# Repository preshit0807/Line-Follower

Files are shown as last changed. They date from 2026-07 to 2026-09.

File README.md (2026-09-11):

# Line Follower

An ESP32-based line-following robot with a custom PCB, 8-channel IR sensor array, and PID-based motor control — tunable live over Wi-Fi from a browser dashboard.

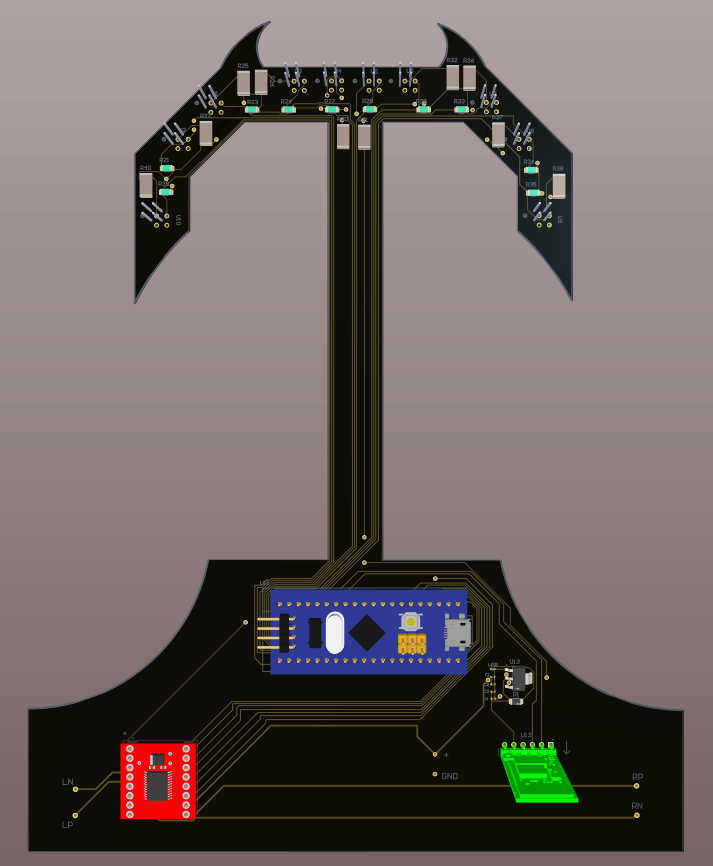
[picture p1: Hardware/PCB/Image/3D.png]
PCB Render


## Overview

The robot uses an 8-sensor IR array to detect a line, computes a weighted line position, and drives two motors through a TB6612-style driver using a PID control loop. The ESP32 hosts its own Wi-Fi access point and a lightweight web server, so PID gains, speeds, and calibration can all be adjusted from a phone or laptop browser — no re-flashing required.

## Features

- 8-channel IR sensor array with automatic min/max calibration
- Weighted line-position calculation with line-lost recovery behavior
- PID motor control (tunable `Kp`, `Ki`, `Kd`, base/turn/max speed)
- ESP32 Wi-Fi Access Point + HTTP server for live control and telemetry
- Browser-based dashboards for sensor visualization and PID tuning
- Custom Altium PCB design with 3D/STEP models
- Standalone test sketches for motors and sensors

## Repository Structure

```
Line-Follower/
├── Software/
│   ├── PID_Code.ino                       # Main firmware — sensing, PID, Wi-Fi control server
│   ├── Motor_test_code.ino                # Standalone motor driver test
│   ├── Sensor_test_code.ino               # Standalone IR sensor calibration/test
│   ├── PID_Tuning_with_dashboard.html     # Browser dashboard for live PID tuning
│   └── Sensor_test_dashboard.html         # Browser dashboard for sensor visualization
└── Hardware/
    └── PCB/
        ├── Altium/                        # Altium schematic and PCB source files
        ├── STEP/                          # 3D STEP model of the PCB
        └── Image/                         # PCB renders and sketches
```

## Hardware

- **MCU:** ESP32
- **Sensors:** 8x analog IR reflectance sensors
- **Motor driver:** Dual H-bridge (TB6612/DRV8833-style), PWM speed control
- **PCB:** Custom-designed in Altium Designer (schematic, layout, and 3D/STEP export included)

| PCB Layout | Sketch |
|---|---|
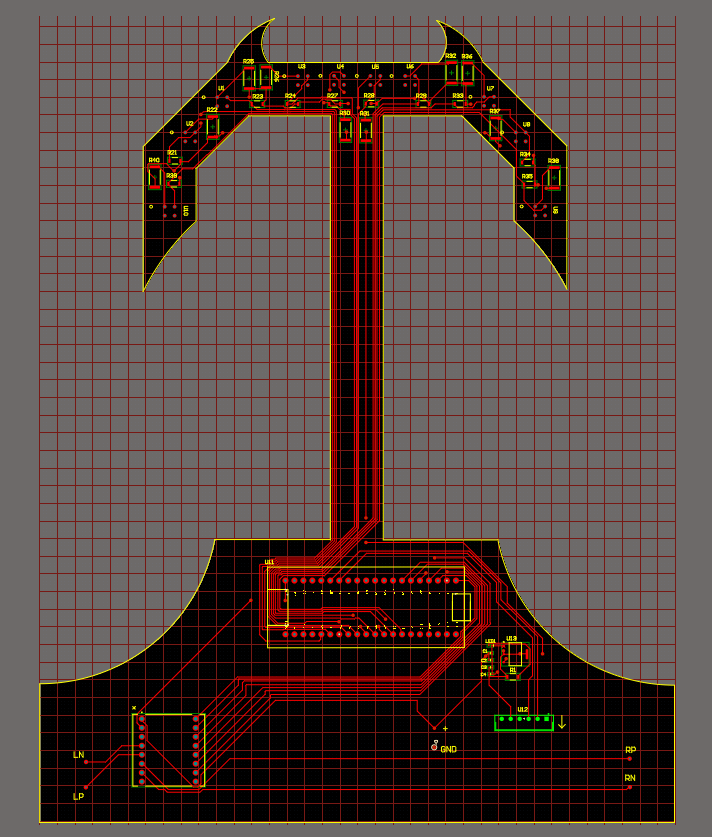
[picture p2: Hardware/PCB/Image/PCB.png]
PCB
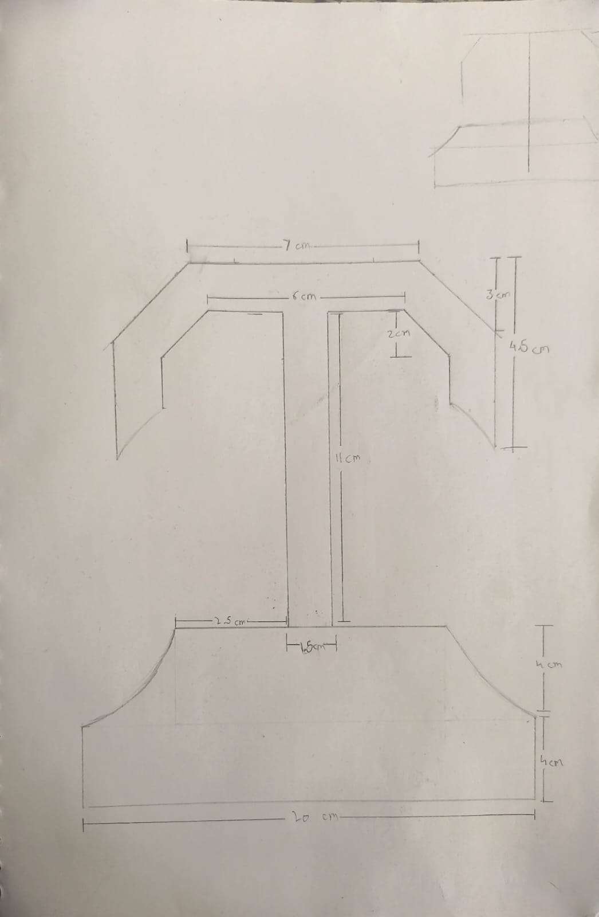
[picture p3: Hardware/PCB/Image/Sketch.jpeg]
Sketch
|  |  |

Altium project files are under `Hardware/PCB/Altium/`. Open `Line Follower.PrjPcbStructure` in Altium Designer to view the schematic (`Sheet1.SchDoc`, `Sheet2.SchDoc`) and board (`PCB1.PcbDoc`). A 3D model is available at `Hardware/PCB/STEP/PCB1.step` for mechanical CAD/enclosure work.

> **Note:** Pin mappings differ slightly between `Motor_test_code.ino`/`Sensor_test_code.ino` and `PID_Code.ino`. Confirm wiring against the pin `#define`s at the top of whichever sketch you flash.

## Getting Started

### 1. Flash the firmware

1. Open the desired `.ino` file in the Arduino IDE (with ESP32 board support installed) or PlatformIO.
2. Select your ESP32 board and port.
3. Upload:
   - `Sensor_test_code.ino` to verify sensor readings and calibration first.
   - `Motor_test_code.ino` to verify motor direction and speed.
   - `PID_Code.ino` for full autonomous line-following.

### 2. Calibrate the sensors

On boot, `PID_Code.ino` runs a 3-second automatic calibration — sweep the sensor array across the line and off it so each sensor sees both its minimum and maximum reflectance. The onboard LED blinks during calibration.

### 3. Connect to the robot

The robot starts a Wi-Fi access point:

- **SSID:** `ESP32-LineFollower`
- **Password:** `12345678`
- **IP:** `192.168.4.1`

Connect a phone or laptop to this network, then open `PID_Tuning_with_dashboard.html` or `Sensor_test_dashboard.html` in a browser to view live telemetry and adjust parameters.

### 4. Tune and run

From the PID tuning dashboard you can adjust `Kp`, `Ki`, `Kd`, base speed, turn speed, and max speed in real time, then send `start` to begin line following and `stop` to halt.

## HTTP API

`PID_Code.ino` exposes a simple HTTP interface on port 80:

| Endpoint | Method | Description |
|---|---|---|
| `/cmd?value=<command>` | GET | Send a command (see below) |
| `/status` | GET | Returns current state as JSON |
| `/packet` | GET | Returns the latest telemetry packet |

**Commands** (via `/cmd?value=`):

| Command | Effect |
|---|---|
| `start` | Enable line following |
| `stop` | Disable and stop motors |
| `cal` | Re-run sensor calibration |
| `Kp=<float>` | Set proportional gain |
| `Ki=<float>` | Set integral gain |
| `Kd=<float>` | Set derivative gain |
| `base=<int>` | Set base motor speed |
| `turn=<int>` | Set turning speed offset |
| `max=<int>` | Set max motor speed |

## License

No license specified yet. Add a `LICENSE` file to define usage terms for this repository.

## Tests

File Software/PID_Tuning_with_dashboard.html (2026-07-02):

Skip to content

≋

# Sensor Dashboard

Wi‑Fi live graphs for all 8 QTR channels.

● Idle

◐

Connect source Start demo stream Stop stream

Wi‑Fi / HTTP

Max points on graph Sample input format IR:120,340,820,150,1600,910,430,140 IR:130,350,840,1490,1900,930,410,145 Parse pasted data Clear charts

PID tuning

Kp Ki Kd Base speed Turning speed Max speed Apply PID

Samples

0

Peak Sensor

Peak Value

0

Estimated Line

## Live sensor traces

Wi‑Fi • ready

## Current sensor bars

## Heatmap view

## Latest packet

IR:0,0,0,0,0,0,0,0

Bot state

Idle

## Log

Ready.

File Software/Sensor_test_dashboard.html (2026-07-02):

# Sensor Dashboard

Live graphs for all 8 QTR channels.

Demo mode Theme

Connect source Start demo stream Stop stream Transport Max points on graph Sample input format IR:120,340,820,1500,1600,910,430,140 IR:130,350,840,1490,1580,900,410,150

Parse pasted data Clear charts

## ESP32 output

Add this line inside your loop to send sensor values in a clean format:

Serial.print("IR:"); for (int i = 0; i < 8; i++) { Serial.print(sensorNorm[i]); if (i < 7) Serial.print(","); } Serial.println();

## What works best

Best option

Laptop + USB Serial

Phone option

Use demo or custom bridge

Expected format

IR:v1,v2,v3,v4,v5,v6,v7,v8

Value range

0 to 1000

Samples

0

Peak sensor

S-

Peak value

0

Estimated line

## Live sensor traces

No data

## Current sensor bars

## Heatmap view

## Latest packet

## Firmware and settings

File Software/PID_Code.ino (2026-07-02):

#include <Arduino.h>
#include <WiFi.h>
#include <WebServer.h>

const char* AP_SSID = "ESP32-LineFollower";
const char* AP_PASS = "12345678";
WebServer server(80);

#define PWMA 19
#define AIN1 21
#define AIN2 22
#define PWMB 23
#define BIN1 18
#define BIN2 13
#define STBY 5
#define PWM_FREQ 5000
#define PWM_RES 8

const int SENSOR_PINS[8] = {34,35,32,33,25,26,27,14};
const int NUM_SENSORS = 8;
const int STATUS_LED = 2;

int sensorMin[NUM_SENSORS];
int sensorMax[NUM_SENSORS];
int sensorNorm[NUM_SENSORS];

float Kp=0.40, Ki=0.00, Kd=1.00;
int baseSpeed=60, turnSpeed=180, maxSpeed=180;
float lastError=0, integral=0;
const float setPoint=3500.0;

bool botEnabled=false;
String currentPacket="IR:0,0,0,0,0,0,0,0 POS:-1";
String currentState="Idle";

void setMotors(int leftSpeed,int rightSpeed){
  leftSpeed=constrain(leftSpeed,-255,255);
  rightSpeed=constrain(rightSpeed,-255,255);
  if(leftSpeed>=0){digitalWrite(AIN1,HIGH);digitalWrite(AIN2,LOW);}
  else{digitalWrite(AIN1,LOW);digitalWrite(AIN2,HIGH);leftSpeed=-leftSpeed;}
  if(rightSpeed>=0){digitalWrite(BIN1,HIGH);digitalWrite(BIN2,LOW);}
  else{digitalWrite(BIN1,LOW);digitalWrite(BIN2,HIGH);rightSpeed=-rightSpeed;}
  ledcWrite(PWMA,leftSpeed);
  ledcWrite(PWMB,rightSpeed);
}

void stopMotors(){ledcWrite(PWMA,0);ledcWrite(PWMB,0);}
void readRawSensors(int*vals){for(int i=0;i<NUM_SENSORS;i++) vals[i]=analogRead(SENSOR_PINS[i]);}
int normalizeSensor(int raw,int index){int range=sensorMax[index]-sensorMin[index];if(range<=0) return 0;return constrain(((sensorMax[index]-raw)*1000)/range,0,1000);}
void readNormalizedSensors(){int raw[NUM_SENSORS];readRawSensors(raw);for(int i=0;i<NUM_SENSORS;i++) sensorNorm[i]=normalizeSensor(raw[i],i);}

int readLinePosition(){
  readNormalizedSensors();
  long weightedSum=0,total=0;
  bool seen=false;
  for(int i=0;i<NUM_SENSORS;i++){
    if(sensorNorm[i]>150) seen=true;
    weightedSum += (long)sensorNorm[i]*(i*1000);
    total += sensorNorm[i];
  }
  if(!seen || total==0) return -1;
  return weightedSum/total;
}

void calibrateSensors(){
  for(int i=0;i<NUM_SENSORS;i++){sensorMin[i]=4095;sensorMax[i]=0;}
  unsigned long start=millis();
  currentState="Calibrating";
  while(millis()-start<3000){
    int raw[NUM_SENSORS];
    readRawSensors(raw);
    for(int i=0;i<NUM_SENSORS;i++){
      if(raw[i]<sensorMin[i]) sensorMin[i]=raw[i];
      if(raw[i]>sensorMax[i]) sensorMax[i]=raw[i];
    }
    digitalWrite(STATUS_LED,!digitalRead(STATUS_LED));
    delay(10);
  }
  digitalWrite(STATUS_LED,LOW);
  currentState="Ready";
}

String buildTelemetry(int pos,const char* state){
  char buf[256];
  snprintf(buf,sizeof(buf),"STATE:%s IR:%d,%d,%d,%d,%d,%d,%d,%d POS:%d",state,
    sensorNorm[0],sensorNorm[1],sensorNorm[2],sensorNorm[3],
    sensorNorm[4],sensorNorm[5],sensorNorm[6],sensorNorm[7],pos);
  return String(buf);
}

void updatePacket(int pos,const char* state){
  currentPacket=buildTelemetry(pos,state);
  Serial.println(currentPacket);
}

void handleCommand(String s){
  s.trim();
  s.replace(" ","");
  if(!s.length()) return;
  if(s=="start"){botEnabled=true;integral=0;lastError=0;currentState="Running";updatePacket(-1,"STARTED");}
  else if(s=="stop"){botEnabled=false;stopMotors();currentState="Stopped";updatePacket(-1,"STOPPED");}
  else if(s=="cal"){calibrateSensors();updatePacket(-1,"CAL_DONE");}
  else if(s.startsWith("Kp=")) Kp=s.substring(3).toFloat();
  else if(s.startsWith("Ki=")) Ki=s.substring(3).toFloat();
  else if(s.startsWith("Kd=")) Kd=s.substring(3).toFloat();
  else if(s.startsWith("base=")) baseSpeed=s.substring(5).toInt();
  else if(s.startsWith("turn=")) turnSpeed=s.substring(5).toInt();
  else if(s.startsWith("max=")) maxSpeed=s.substring(4).toInt();
  currentState="Ready";
}

void handleCmd(){
  if(!server.hasArg("value")){server.send(400,"text/plain","missing value"); return;}
  handleCommand(server.arg("value"));
  server.send(200,"text/plain","OK");
}

void handleStatus(){ server.send(200,"application/json", String("{\"state\":\"")+currentState+"\",\"botEnabled\":"+(botEnabled?"true":"false")+"}"); }
void handlePacket(){ server.send(200,"text/plain",currentPacket); }

void setup(){
  Serial.begin(115200);
  pinMode(STATUS_LED,OUTPUT);
  pinMode(AIN1,OUTPUT); pinMode(AIN2,OUTPUT); pinMode(BIN1,OUTPUT); pinMode(BIN2,OUTPUT); pinMode(STBY,OUTPUT);
  digitalWrite(STBY,HIGH);
  ledcAttach(PWMA,PWM_FREQ,PWM_RES);
  ledcAttach(PWMB,PWM_FREQ,PWM_RES);

  WiFi.mode(WIFI_AP);
  WiFi.softAP(AP_SSID,AP_PASS);

  calibrateSensors();
  server.on("/cmd", handleCmd);
  server.on("/status", handleStatus);
  server.on("/packet", handlePacket);
  server.begin();
  currentState="Ready";
  updatePacket(-1,"READY");
}

void loop(){
  server.handleClient();

  if(!botEnabled){
    stopMotors();
    delay(5);
    return;
  }

  int position=readLinePosition();
  const char* state="FOLLOW";

  if(position==-1){
    state="LOST";
    setMotors(50,50);
  } else if(position<3000){
    state="LEFT";
    setMotors(baseSpeed-turnSpeed, baseSpeed+turnSpeed);
  } else if(position>4000){
    state="RIGHT";
    setMotors(baseSpeed+turnSpeed, baseSpeed-turnSpeed);
  } else {
    float error=position-setPoint;
    integral += error;
    integral = constrain(integral,-2500,2500);
    float derivative=error-lastError;
    lastError=error;
    float correction=Kp*error+Ki*integral+Kd*derivative;
    int leftMotor=constrain((int)(baseSpeed+correction),0,maxSpeed);
    int rightMotor=constrain((int)(baseSpeed-correction),0,maxSpeed);
    setMotors(leftMotor,rightMotor);
  }

  updatePacket(position,state);
  delay(10);
}

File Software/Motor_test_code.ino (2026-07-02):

#include <Arduino.h>

#define PWMA 32
#define AIN1 33
#define AIN2 13
#define PWMB 21
#define BIN1 22
#define BIN2 23
#define STBY 18

#define PWM_FREQ 5000
#define PWM_RES 8
#define PWM_CH_A 0
#define PWM_CH_B 1

void setLeftMotor(int speedVal) {
  speedVal = constrain(speedVal, -255, 255);
  if (speedVal >= 0) {
    digitalWrite(AIN1, HIGH);
    digitalWrite(AIN2, LOW);
  } else {
    digitalWrite(AIN1, LOW);
    digitalWrite(AIN2, HIGH);
    speedVal = -speedVal;
  }
  ledcWrite(PWM_CH_A, speedVal);
}

void setRightMotor(int speedVal) {
  speedVal = constrain(speedVal, -255, 255);
  if (speedVal >= 0) {
    digitalWrite(BIN1, HIGH);
    digitalWrite(BIN2, LOW);
  } else {
    digitalWrite(BIN1, LOW);
    digitalWrite(BIN2, HIGH);
    speedVal = -speedVal;
  }
  ledcWrite(PWM_CH_B, speedVal);
}

void stopAll() {
  ledcWrite(PWM_CH_A, 0);
  ledcWrite(PWM_CH_B, 0);
}

void setup() {
  Serial.begin(115200);

  pinMode(AIN1, OUTPUT);
  pinMode(AIN2, OUTPUT);
  pinMode(BIN1, OUTPUT);
  pinMode(BIN2, OUTPUT);
  pinMode(STBY, OUTPUT);

  digitalWrite(STBY, HIGH);

  ledcSetup(PWM_CH_A, PWM_FREQ, PWM_RES);
  ledcSetup(PWM_CH_B, PWM_FREQ, PWM_RES);
  ledcAttachPin(PWMA, PWM_CH_A);
  ledcAttachPin(PWMB, PWM_CH_B);

  Serial.println("Motor check start");
}

void loop() {
  Serial.println("Left motor forward");
  setLeftMotor(150);
  stopAll();
  delay(1000);
  setLeftMotor(150);
  delay(1500);
  stopAll();
  delay(1000);

  Serial.println("Left motor reverse");
  setLeftMotor(-150);
  delay(1500);
  stopAll();
  delay(1000);

  Serial.println("Right motor forward");
  setRightMotor(150);
  delay(1500);
  stopAll();
  delay(1000);

  Serial.println("Right motor reverse");
  setRightMotor(-150);
  delay(1500);
  stopAll();
  delay(1000);

  Serial.println("Both motors forward");
  setLeftMotor(150);
  setRightMotor(150);
  delay(2000);
  stopAll();
  delay(1500);
}

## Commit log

2026-07-02 Add hardware schematics
2026-07-14 Add professional line follower PCB design
    [PCB1.PcbDoc, Sheet1.SchDoc, Sheet2.SchDoc]
